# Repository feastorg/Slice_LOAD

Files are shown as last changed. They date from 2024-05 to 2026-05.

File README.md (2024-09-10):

# Load Cell Amplifier Slice

Load Cell Amplifier Slice for BREAD.

## Introduction

[Short introduction on the project.]

## Usage

[Explain how to use the project. Include examples and screenshots if applicable.]

## Documentation

Please refer to the [docs](/docs) for more info.

---

<div align="center">
  <p>
    
    
  </p>
</div>

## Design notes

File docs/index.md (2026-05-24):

---
title: "Slice LOAD Documentation"
description: "Overview and entry page for Slice LOAD project documentation."
nav_exclude: true
---

Welcome to the Slice LOAD project documentation.

## Board Renders

<figure style="display:inline-block; text-align:center; margin:10px;">
  Board Top
  <figcaption>Top</figcaption>
</figure>

<figure style="display:inline-block; text-align:center; margin:10px;">
  Board Bottom
  <figcaption>Bottom</figcaption>
</figure>

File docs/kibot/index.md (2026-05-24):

---
title: "KiBot Outputs"
description: "Index for KiBot-generated PCB artifacts."
layout: "page"
---

These are the docs & KiBot Outputs for Slice LOAD

The following files were generated from the latest PCB build:

- [Schematic.pdf](./Schematic.pdf)
- [PCB.pdf](./PCB.pdf)
- [kibot.log](./kibot.log)
- [BREAD_Slice-bom.html](./BREAD_Slice-bom.html)
- [BREAD_Slice-ibom.html](./BREAD_Slice-ibom.html)

_Last updated automatically by KiBot via GitHub Actions._

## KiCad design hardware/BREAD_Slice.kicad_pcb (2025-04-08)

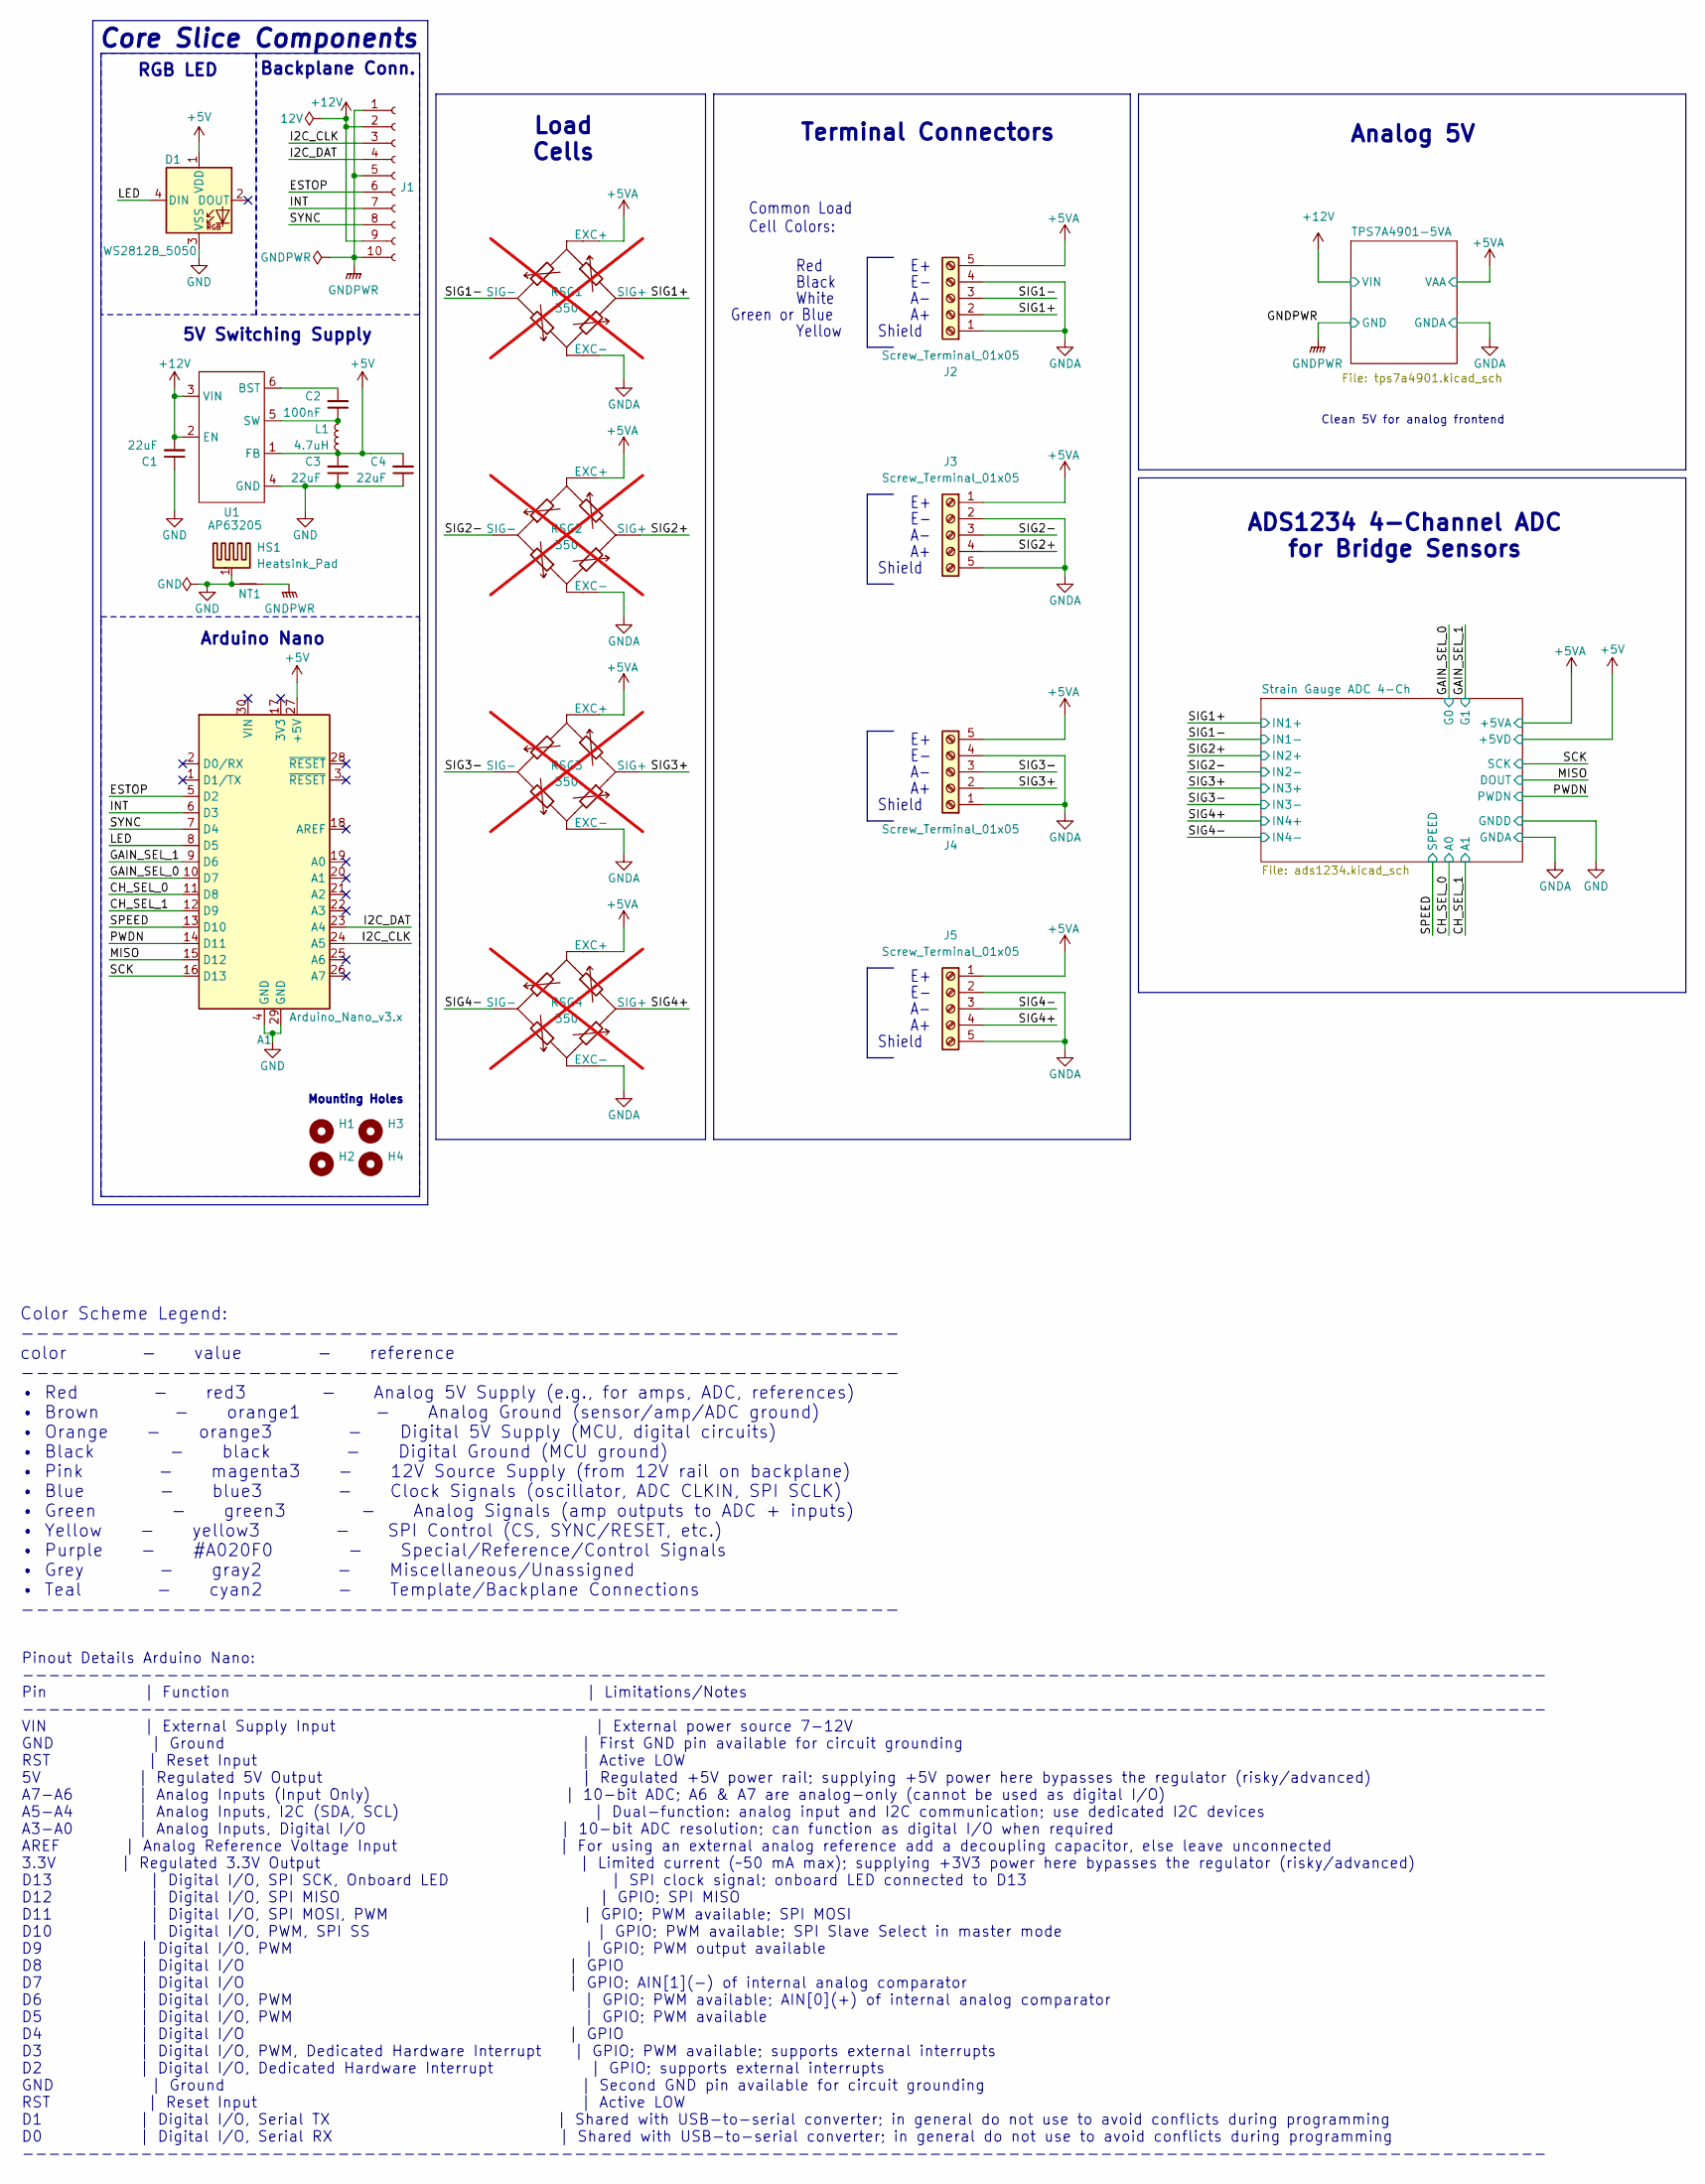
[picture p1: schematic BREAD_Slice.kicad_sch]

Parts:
A1: Arduino_Nano_v3.x; Arduino_Nano
C1, C3, C4: 22uF; C_1206_3216Metric
C2: 100nF; C_1206_3216Metric
D1: WS2812B_5050; WS2812-5050-4PIN
H1, H2, H3, H4: MountingHole; MountingHole_5mm
HS1: Heatsink_Pad; Thermal Pad
J1: Conn_01x10_Female; PinSocket_1x10_P2.54mm_Horizontal
J2, J3, J4, J5: Screw_Terminal_01x05; TerminalBlock_4Ucon_1x05_P3.50mm_Horizontal
L1: 4.7uH; L_1210_3225Metric
NT1: NetTie_2; NetTie-2_SMD_Pad2.0mm
RSG1, RSG2, RSG3, RSG4: 350; not fitted
U1: AP63205; TSOT-23-6

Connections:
+5V: A1.27 (+5V), C3.2, C4.2, D1.1 (VDD), L1.2, U1.1 (FB); also elsewhere on the board
+5VA: J2.5, J3.1, J4.5, J5.1, RSG1.1 (EXC+), RSG2.1 (EXC+), RSG3.1 (EXC+), RSG4.1 (EXC+); also elsewhere on the board
+12V: C1.2, J1.2, J1.9, U1.2 (EN), U1.3 (VIN); also elsewhere on the board
/CH_SEL_0: A1.11 (D8); also elsewhere on the board
/CH_SEL_1: A1.12 (D9); also elsewhere on the board
/ESTOP: A1.5 (D2), J1.6
/GAIN_SEL_0: A1.10 (D7); also elsewhere on the board
/GAIN_SEL_1: A1.9 (D6); also elsewhere on the board
/I2C_CLK: A1.24 (A5), J1.3
/I2C_DAT: A1.23 (A4), J1.4
/INT: A1.6 (D3), J1.7
/LED: A1.8 (D5), D1.4 (DIN)
/MISO: A1.15 (D12); also elsewhere on the board
/PWDN: A1.14 (D11); also elsewhere on the board
/SCK: A1.16 (D13); also elsewhere on the board
/SIG1+: J2.2, RSG1.3 (SIG+); also elsewhere on the board
/SIG1-: J2.3, RSG1.4 (SIG-); also elsewhere on the board
/SIG2+: J3.4, RSG2.3 (SIG+); also elsewhere on the board
/SIG2-: J3.3, RSG2.4 (SIG-); also elsewhere on the board
/SIG3+: J4.2, RSG3.3 (SIG+); also elsewhere on the board
/SIG3-: J4.3, RSG3.4 (SIG-); also elsewhere on the board
/SIG4+: J5.4, RSG4.3 (SIG+); also elsewhere on the board
/SIG4-: J5.3, RSG4.4 (SIG-); also elsewhere on the board
/SPEED: A1.13 (D10); also elsewhere on the board
/SYNC: A1.7 (D4), J1.8
GND: A1.4 (GND), A1.29 (GND), C1.1, C3.1, C4.1, D1.3 (VSS), HS1.1, NT1.1, U1.4 (GND); also elsewhere on the board
GNDA: J2.1, J2.4, J3.2, J3.5, J4.1, J4.4, J5.2, J5.5, RSG1.2 (EXC-), RSG2.2 (EXC-), RSG3.2 (EXC-), RSG4.2 (EXC-); also elsewhere on the board
GNDPWR: J1.1, J1.5, J1.10, NT1.2; also elsewhere on the board
unnamed: C2.2, U1.6 (BST)
unnamed: C2.1, L1.1, U1.5 (SW)

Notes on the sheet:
5V Switching Supply
Red
Shield
Common Load Cell Colors:
Analog 5V
Pinout Details Arduino Nano: -------------------------------------------------------------------------------------------------------------------- Pin | Function | Limitations/Notes -------------------------------------------------------------------------------------------------------------------- V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
RGB LED
White
Color Scheme Legend: ---------------------------------------------------------- color - value - reference ---------------------------------------------------------- • Red - red3 - Analog 5V Supply (e.g., for amps, ADC, references) • Brown - orange1 - Analog Ground (sensor/amp/ADC ground) • Orange -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
Green or Blue
Yellow
Terminal Connectors
Black
Core Slice Components
ADS1234 4-Channel ADC for Bridge Sensors
Arduino Nano
Clean 5V for analog frontend
Mounting Holes
Backplane Conn.
Load Cells

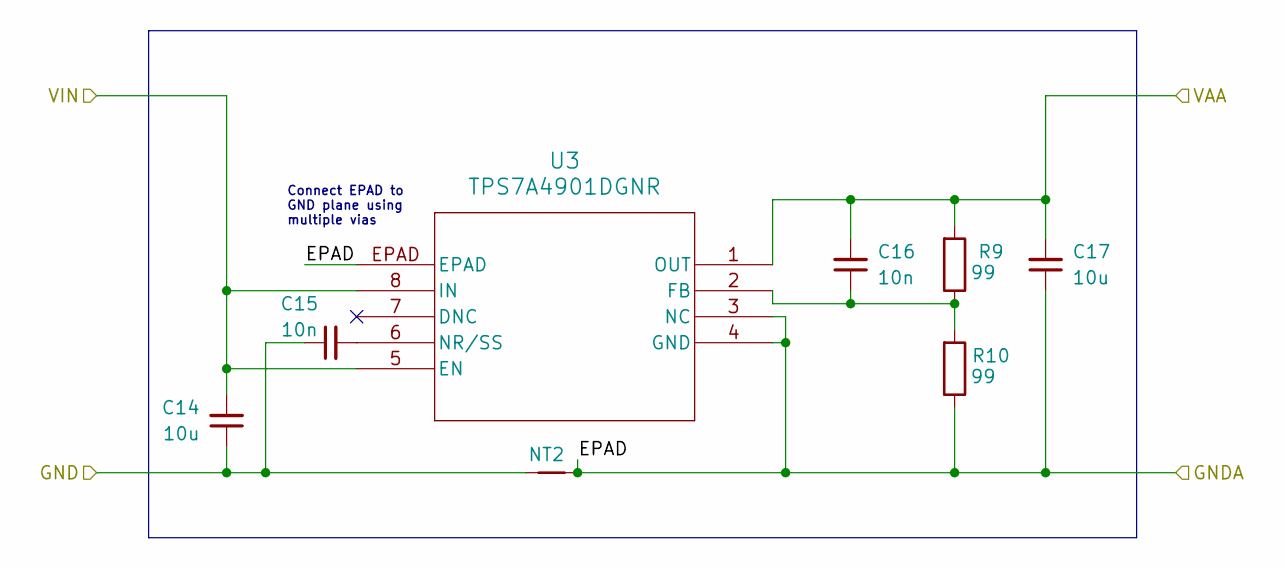
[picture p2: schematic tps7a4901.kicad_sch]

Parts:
C14, C17: 10u; C_0805_2012Metric_Pad1.18x1.45mm_HandSolder
C15, C16: 10n; C_0805_2012Metric_Pad1.18x1.45mm_HandSolder
NT2: NetTie_2; NetTie-2_SMD_Pad2.0mm
R9, R10: 99; R_0805_2012Metric_Pad1.20x1.40mm_HandSolder
U3: TPS7A4901DGNR; DGN8_1P89X1P57

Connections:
+5VA: C16.2, C17.2, R9.2, U3.1 (OUT); also elsewhere on the board
+12V: C14.2, U3.5 (EN), U3.8 (IN); also elsewhere on the board
GNDA: C17.1, NT2.2, R10.1, U3.3 (NC), U3.4 (GND), U3.EPAD; also elsewhere on the board
GNDPWR: C14.1, C15.1, NT2.1; also elsewhere on the board
unnamed: C16.1, R9.1, R10.2, U3.2 (FB)
unnamed: C15.2, U3.6 (NR/SS)

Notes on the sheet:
Connect EPAD to GND plane using multiple vias

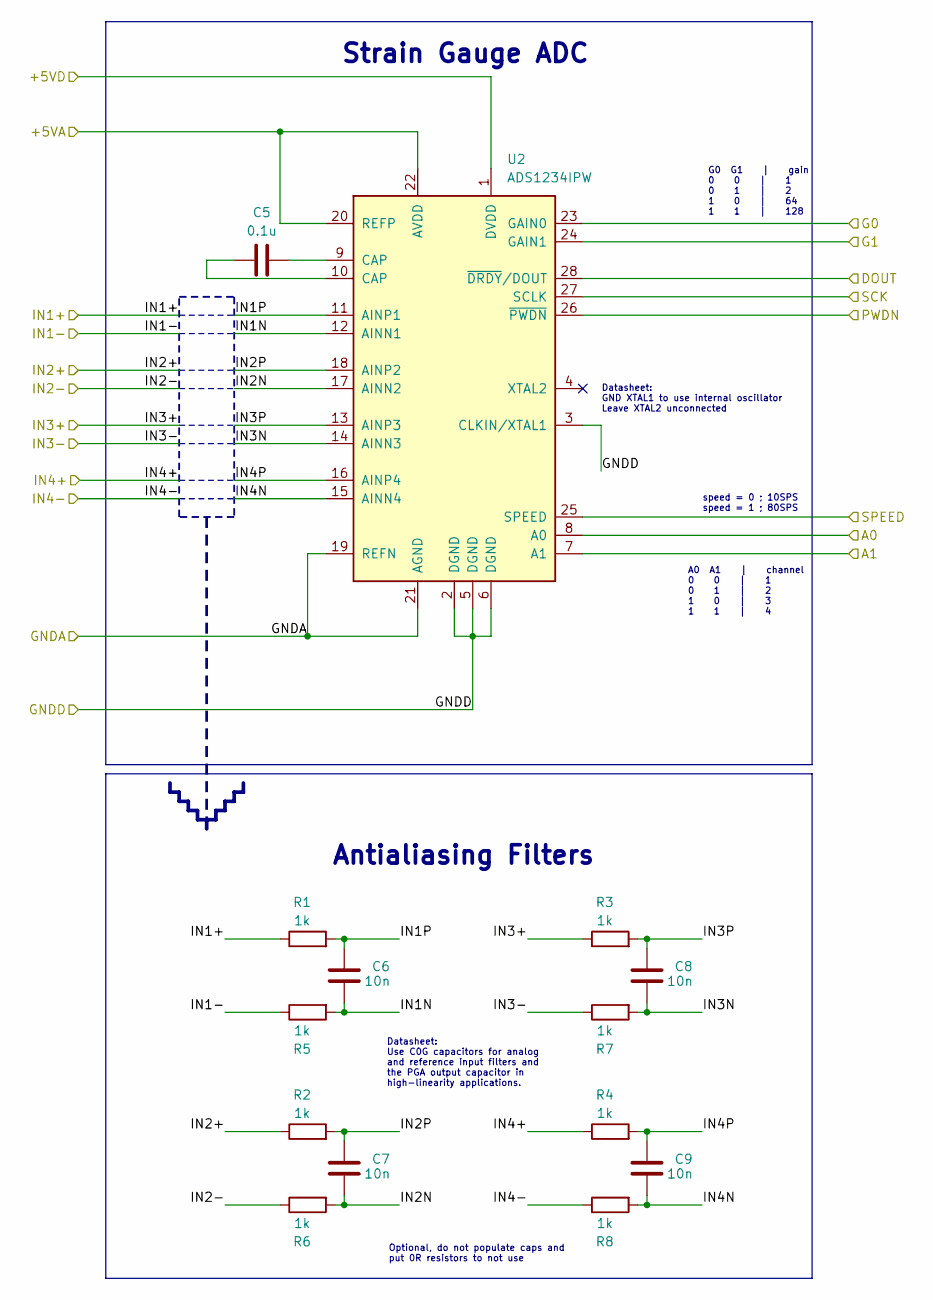
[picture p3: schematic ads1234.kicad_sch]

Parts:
C5: 0.1u; C_0603_1608Metric_Pad1.08x0.95mm_HandSolder
C6, C7, C8, C9: 10n; C_0603_1608Metric_Pad1.08x0.95mm_HandSolder
R1, R2, R3, R4, R5, R6, R7, R8: 1k; R_0603_1608Metric_Pad0.98x0.95mm_HandSolder
U2: ADS1234IPW; TSSOP-28_4.4x9.7mm_P0.65mm

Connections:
+5V: U2.1 (DVDD); also elsewhere on the board
+5VA: U2.20 (REFP), U2.22 (AVDD); also elsewhere on the board
/CH_SEL_0: U2.8 (A0); also elsewhere on the board
/CH_SEL_1: U2.7 (A1); also elsewhere on the board
/GAIN_SEL_0: U2.23 (GAIN0); also elsewhere on the board
/GAIN_SEL_1: U2.24 (GAIN1); also elsewhere on the board
/MISO: U2.28 (~DRDY/DOUT); also elsewhere on the board
/PWDN: U2.26 (~PWDN); also elsewhere on the board
/SCK: U2.27 (SCLK); also elsewhere on the board
/SIG1+: R1.1; also elsewhere on the board
/SIG1-: R5.1; also elsewhere on the board
/SIG2+: R2.1; also elsewhere on the board
/SIG2-: R6.1; also elsewhere on the board
/SIG3+: R3.1; also elsewhere on the board
/SIG3-: R7.1; also elsewhere on the board
/SIG4+: R4.1; also elsewhere on the board
/SIG4-: R8.1; also elsewhere on the board
/SPEED: U2.25 (SPEED); also elsewhere on the board
/Strain Gauge ADC 4-Ch/IN1N: C6.1, R5.2, U2.12 (AINN1)
/Strain Gauge ADC 4-Ch/IN1P: C6.2, R1.2, U2.11 (AINP1)
/Strain Gauge ADC 4-Ch/IN2N: C7.1, R6.2, U2.17 (AINN2)
/Strain Gauge ADC 4-Ch/IN2P: C7.2, R2.2, U2.18 (AINP2)
/Strain Gauge ADC 4-Ch/IN3N: C8.1, R7.2, U2.14 (AINN3)
/Strain Gauge ADC 4-Ch/IN3P: C8.2, R3.2, U2.13 (AINP3)
/Strain Gauge ADC 4-Ch/IN4N: C9.1, R8.2, U2.15 (AINN4)
/Strain Gauge ADC 4-Ch/IN4P: C9.2, R4.2, U2.16 (AINP4)
GND: U2.2 (DGND), U2.3 (CLKIN/XTAL1), U2.5 (DGND), U2.6 (DGND); also elsewhere on the board
GNDA: U2.19 (REFN), U2.21 (AGND); also elsewhere on the board
unnamed: C5.1, U2.10 (CAP)
unnamed: C5.2, U2.9 (CAP)

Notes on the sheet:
Optional, do not populate caps and put 0R resistors to not use
Datasheet: GND XTAL1 to use internal oscillator Leave XTAL2 unconnected
A0 A1 | channel 0 0 | 1 0 1 | 2 1 0 | 3 1 1 | 4
Antialiasing Filters
Datasheet: Use C0G capacitors for analog and reference input filters and the PGA output capacitor in high-linearity applications.
Strain Gauge ADC
G0 G1 | gain 0 0 | 1 0 1 | 2 1 0 | 64 1 1 | 128
speed = 0 ; 10SPS speed = 1 ; 80SPS

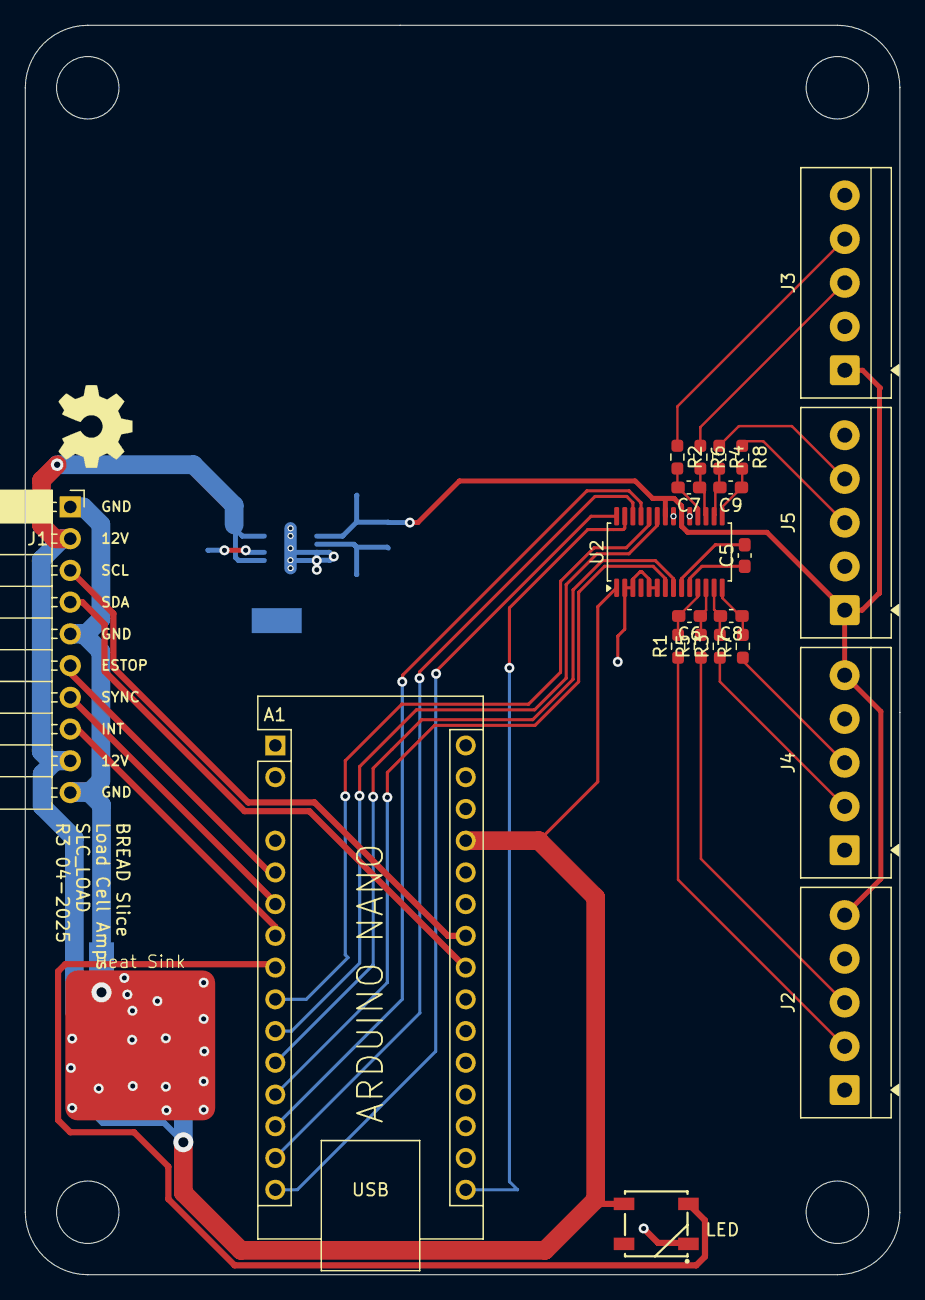
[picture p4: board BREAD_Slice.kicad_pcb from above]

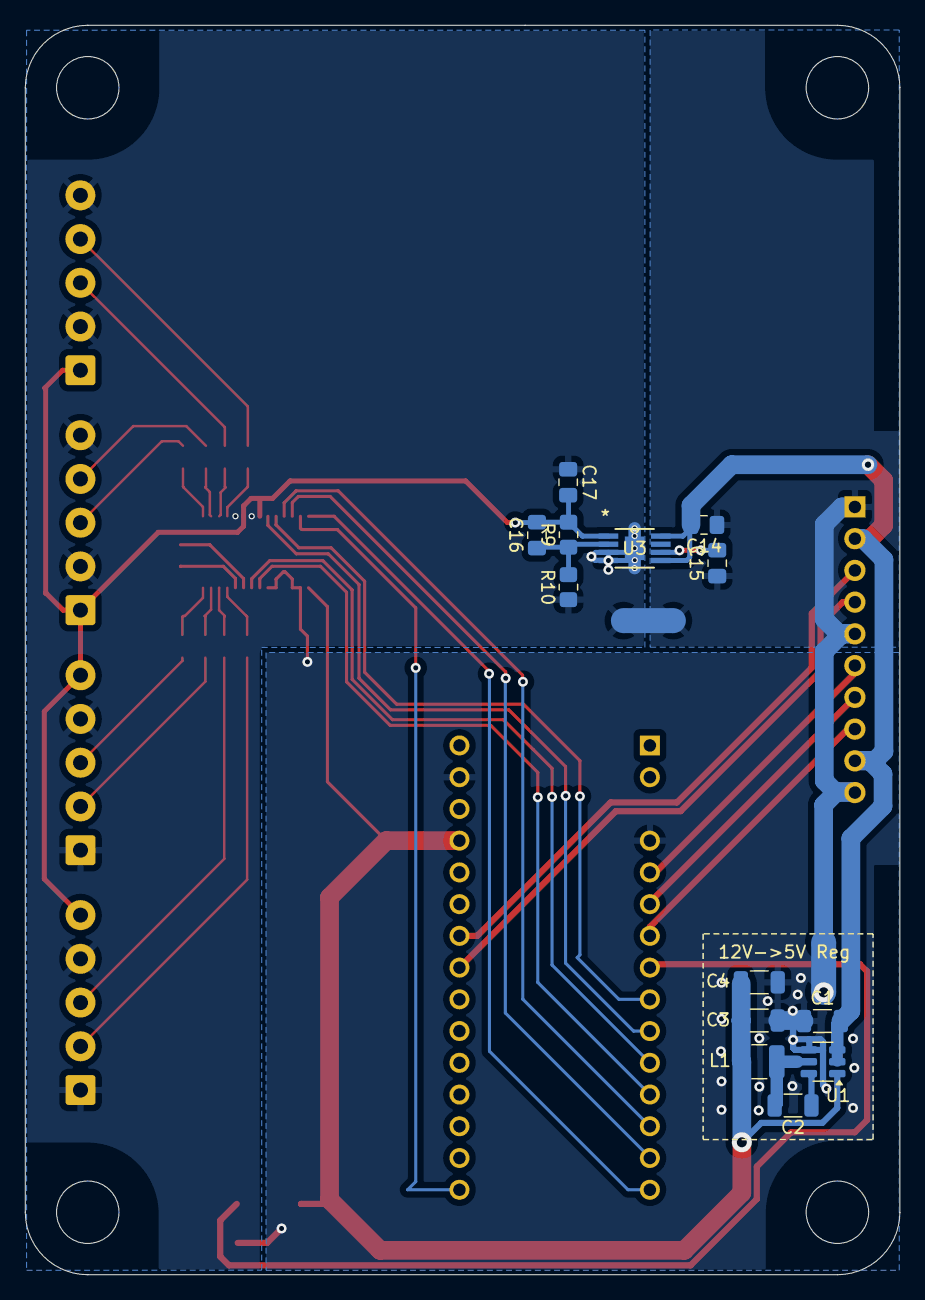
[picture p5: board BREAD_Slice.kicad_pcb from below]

Board: 2 copper layers, 70.0 x 100.0 mm, 42 parts (15 on the bottom side), 42 nets.

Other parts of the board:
Logo1: Logo_Open_Hardware_Small; OSHW-Symbol_6.7x6mm_SilkScreen

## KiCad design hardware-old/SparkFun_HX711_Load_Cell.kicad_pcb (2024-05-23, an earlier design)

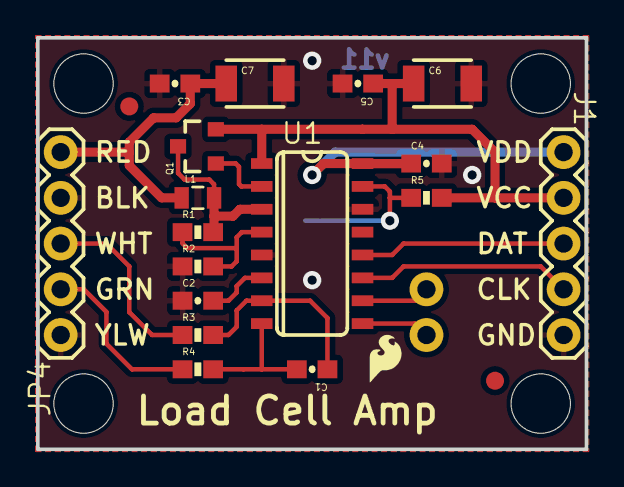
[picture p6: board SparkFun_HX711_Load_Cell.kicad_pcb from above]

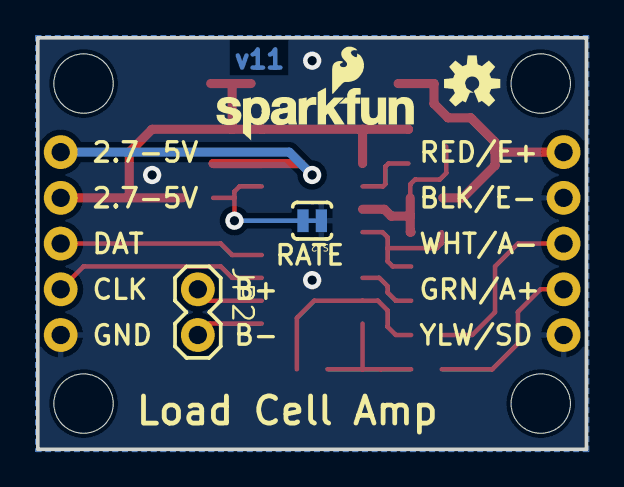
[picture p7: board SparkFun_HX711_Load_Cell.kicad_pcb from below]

Board: 2 copper layers, 30.5 x 22.9 mm, 30 parts (4 on the bottom side), 17 nets.

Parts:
C1, C2, C3, C4, C5: 0.1uF; 0603-CAP
C6, C7: 10uF; 1210
FID1, FID2: FIDUCIAL1X2; FIDUCIAL-1X2
FRAME1: FRAME-LETTER; CREATIVE_COMMONS
J1: 1X05
JP2: 1X02
JP4: 1X05
L1: 3.3uH; 0805
LOGO1: SFE_LOGO_NAME_FLAME.1_INCH; SFE_LOGO_NAME_FLAME_.1
LOGO3: SFE_LOGO_FLAME.1_INCH; SFE_LOGO_FLAME_.1
Q1: MMBT4403; SOT23-3
R1: 20k; 0603-RES
R2: 8.2K; 0603-RES
R3, R4: 100; 0603-RES
R5: 10K; 0603-RES
SJ2: PAD-JUMPER-2-NC_BY_TRACE_YES_SILK
STANDOFF1, STANDOFF2, STANDOFF3, STANDOFF4: STAND-OFF
U1: HX711; SO16
U7: OSHW-LOGOS; OSHW-LOGO-S
U$1: REVISION

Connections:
A+: JP4.2, R4.1
A-: JP4.3, R3.1
AVDD: C3.1, C7.1, JP4.5, L1.1
B+: JP2.1, U1.10
B-: JP2.2, U1.9
DAT: J1.3, U1.12
GND: C2.1, C3.2, C4.2, C5.2, C6.2, C7.2, J1.5, JP4.1, JP4.4, R2.1, SJ2.1, U1.5, U1.14
unnamed: R5.1, SJ2.2, U1.15
unnamed: C1.1, R3.2, U1.7
unnamed: C1.2, R4.2, U1.8
unnamed: Q1.1, U1.2
unnamed: L1.2, Q1.3, R1.2, U1.3
unnamed: R1.1, R2.2, U1.4
unnamed: C2.2, U1.6
SCK: J1.4, U1.11
VCC: C5.1, C6.1, J1.2, Q1.2, R5.2, U1.1
VDD: C4.1, J1.1, U1.16

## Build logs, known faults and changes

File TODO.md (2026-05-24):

# TODO

## Pass 1 — CI Pipeline

- [x] Pipeline added
- [x] ERC: FAIL — 1 error (power_pin_not_driven)
- [x] DRC: PASS
- [ ] Fab: SKIPPED (blocked by ERC pre-flight)
- [ ] gen-kibot-index: SKIPPED
- [ ] deploy-pages: SKIPPED

## Pass 2 — Pre-Fab Review

- [ ] Fix 1x power_pin_not_driven ERC error (input power pin not driven by output)
- [ ] Verify BOM completeness and sourcing
- [ ] Confirm board outline and mounting holes
- [ ] Footprint verification against datasheets
- [ ] Design review sign-off

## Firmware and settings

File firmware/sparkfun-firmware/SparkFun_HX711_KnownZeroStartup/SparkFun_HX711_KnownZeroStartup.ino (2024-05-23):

/*
 Example using the SparkFun HX711 breakout board with a scale
 By: Nathan Seidle
 SparkFun Electronics
 Date: November 19th, 2014
 License: This code is public domain but you buy me a beer if you use this and we meet someday (Beerware license).
 
 Most scales require that there be no weight on the scale during power on. This sketch shows how to pre-load tare values
 so that you don't have to clear the scale between power cycles. This is good if you have something on the scale 
 all the time and need to reset the Arduino and not need to tare the scale.
 
 This example code uses bogde's excellent library: https://github.com/bogde/HX711
 bogde's library is released under a GNU GENERAL PUBLIC LICENSE
 
 The HX711 does one thing well: read load cells. The breakout board is compatible with any wheat-stone bridge
 based load cell which should allow a user to measure everything from a few grams to tens of tons.

 Arduino pin 2 -> HX711 CLK
 3 -> DOUT
 5V -> VCC
 GND -> GND
 
 The HX711 board can be powered from 2.7V to 5V so the Arduino 5V power should be fine.
 
*/

#include "HX711.h" //This library can be obtained here http://librarymanager/All#Avia_HX711

#define calibration_factor -7050.0 //This value is obtained using the SparkFun_HX711_Calibration sketch
#define zero_factor 8421804 //This large value is obtained using the SparkFun_HX711_Calibration sketch

#define LOADCELL_DOUT_PIN  3
#define LOADCELL_SCK_PIN  2

HX711 scale;

void setup() {
  Serial.begin(9600);
  Serial.println("Demo of zeroing out a scale from a known value");

  scale.begin(LOADCELL_DOUT_PIN, LOADCELL_SCK_PIN);
  scale.set_scale(calibration_factor); //This value is obtained by using the SparkFun_HX711_Calibration sketch
  scale.set_offset(zero_factor); //Zero out the scale using a previously known zero_factor

  Serial.println("Readings:");
}

void loop() {
  Serial.print("Reading: ");
  Serial.print(scale.get_units(), 1); //scale.get_units() returns a float
  Serial.print(" lbs"); //You can change to kg but you'll need to change the calibration_factor
  Serial.println();
}

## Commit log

2025-04-08 finished first pass of schematic and board
    [BREAD_Slice.kicad_pcb, BREAD_Slice.kicad_sch, SparkFun_HX711_Load_Cell.kicad_pcb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]
2025-04-19 minor tweaks
    [BREAD_Slice.kicad_sch, tps7a4901.kicad_sch]
2026-04-18 chore: minor updates
    [BREAD_Slice.kicad_sch, ads1234.kicad_sch, tps7a4901.kicad_sch]

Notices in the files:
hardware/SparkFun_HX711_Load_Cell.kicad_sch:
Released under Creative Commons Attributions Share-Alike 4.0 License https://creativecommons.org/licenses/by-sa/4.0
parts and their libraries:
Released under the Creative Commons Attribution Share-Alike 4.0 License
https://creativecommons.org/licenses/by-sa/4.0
